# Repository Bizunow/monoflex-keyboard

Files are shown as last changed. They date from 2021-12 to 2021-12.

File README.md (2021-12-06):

# Monoflex keyboard

This repo contains case, plate, foam and PCB  design files for a Monoflex keyboard.

Case, plates and foam designed by me ([Bizunow](https://github.com/Bizunow)) and PCB designed by [keyten](https://github.com/KeyTen1).

Maintained by [Bizunow](https://github.com/Bizunow) & [ILWrites](https://github.com/pikeeb)

QMK Firmware source available on ILWrites' [Monoflex QMK branch](https://github.com/PiKeeb/qmk_firmware/tree/monoflex/keyboards/monoflex60)

Huge thanks to all, who helped me design this keyboard.

Licenced under WTFPL v2


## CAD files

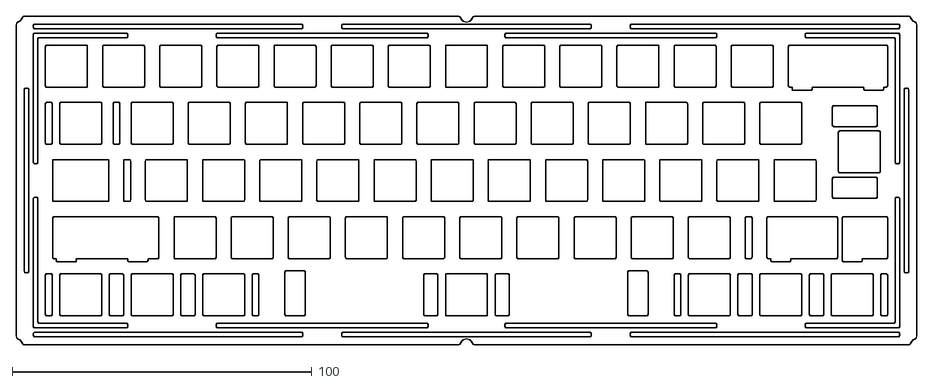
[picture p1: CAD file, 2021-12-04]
case_design/plates/carbon/full_plate_carbon_iso.dxf
300.1 x 109.6

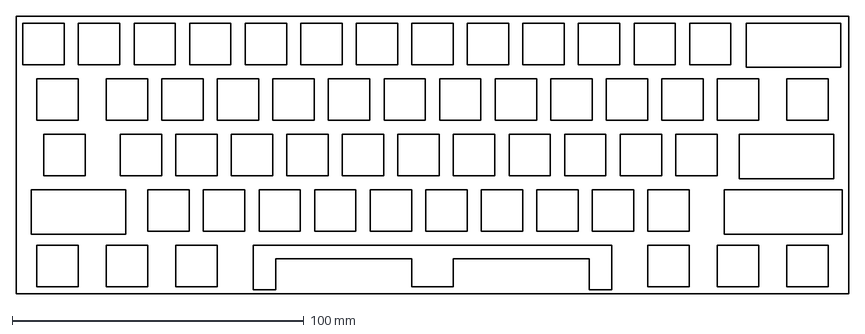
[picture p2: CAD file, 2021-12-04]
case_design/foam/foam_pcb_plate_full_tsangan.dxf
285.5 x 95.1 mm

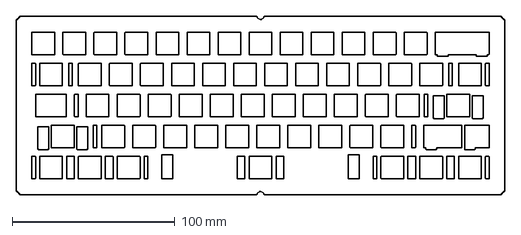
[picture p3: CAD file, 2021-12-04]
case_design/plates/pom/full_plate_pom_tsangan.dxf
300.1 x 109.6 mm

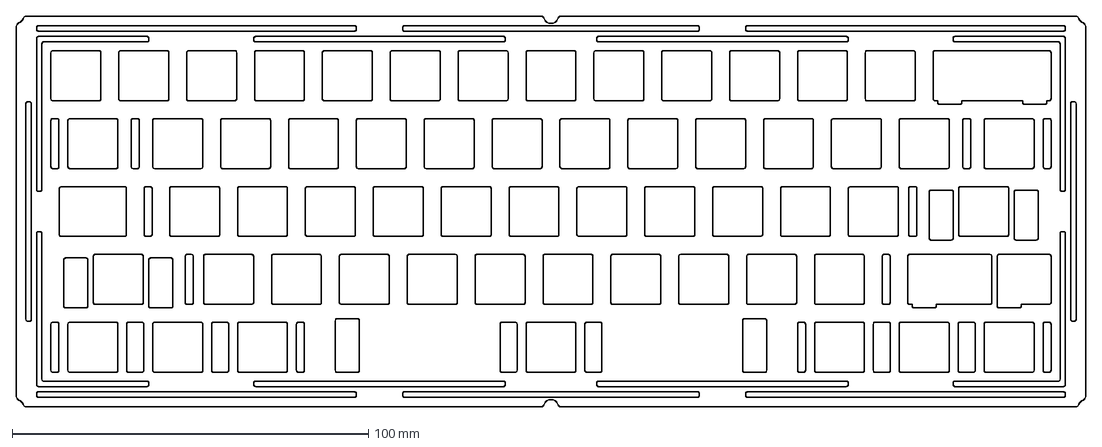
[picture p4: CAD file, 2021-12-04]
case_design/plates/carbon/full_plate_carbon.dxf
300.1 x 109.6 mm

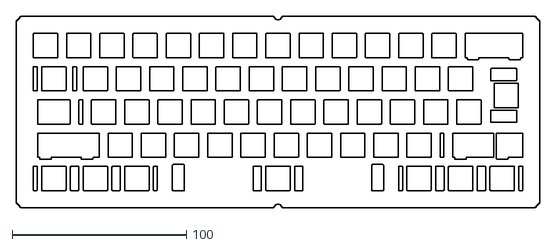
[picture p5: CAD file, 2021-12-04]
case_design/plates/pom/full_plate_pom_iso.dxf
300.1 x 109.6

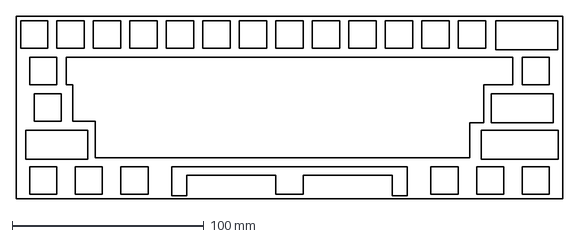
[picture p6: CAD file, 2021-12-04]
case_design/foam/foam_pcb_plate_half_tsangan.dxf
285.5 x 95.1 mm

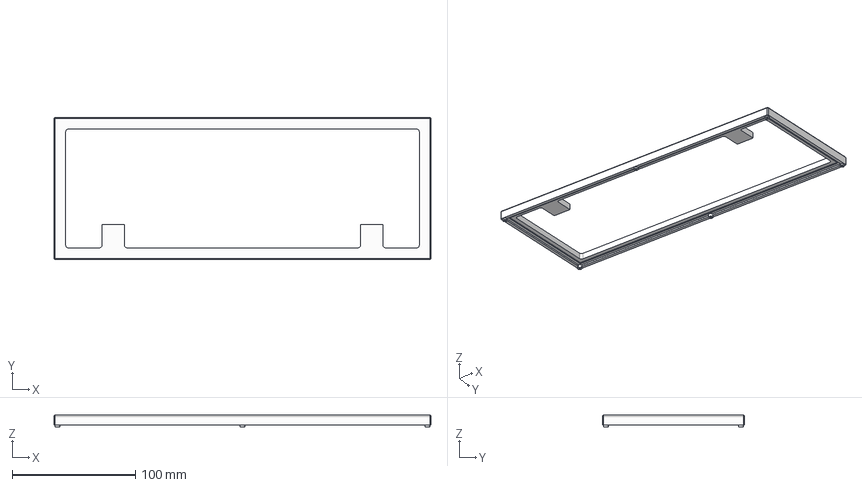
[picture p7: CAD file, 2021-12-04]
case_design/monoflex_top_wkl.step
305.8 x 115.2 x 9.60 mm

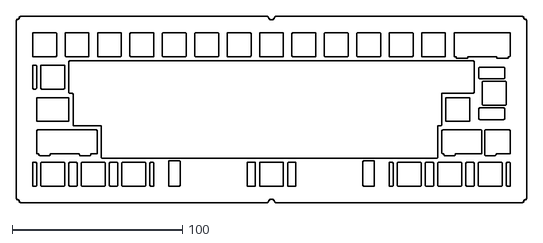
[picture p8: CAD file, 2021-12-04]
case_design/plates/pom/half_plate_pom_iso.dxf
300.1 x 109.6

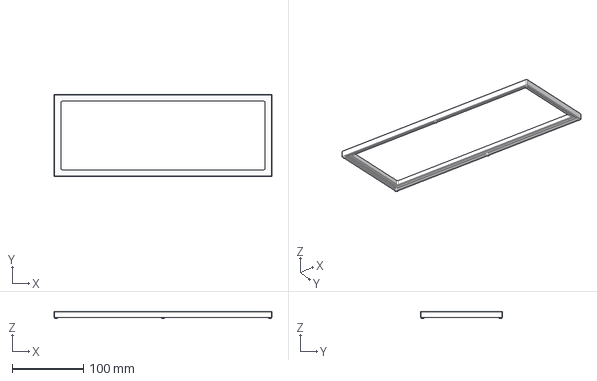
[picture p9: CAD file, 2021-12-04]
case_design/monoflex_top_ansi.step
305.8 x 115.2 x 9.60 mm

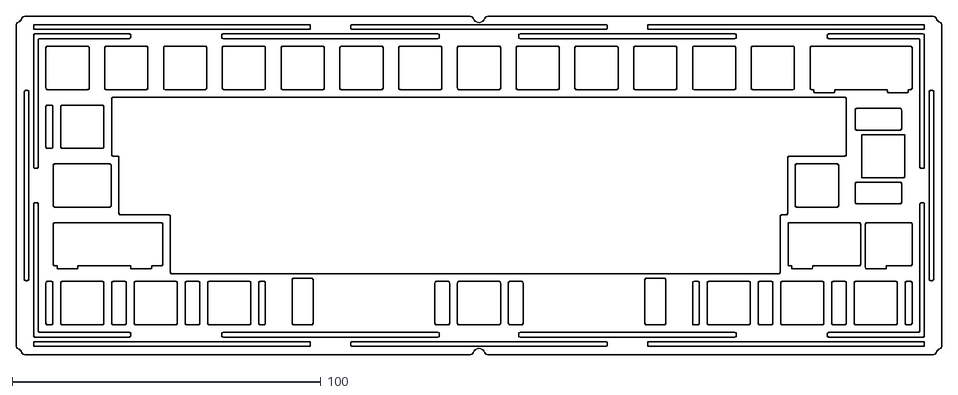
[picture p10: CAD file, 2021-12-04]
case_design/plates/carbon/half_plate_carbon_iso.dxf
300.1 x 109.6

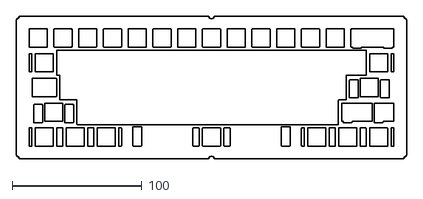
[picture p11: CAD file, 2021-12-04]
case_design/plates/pom/half_plate_pom_tsangan.dxf
300.1 x 109.6

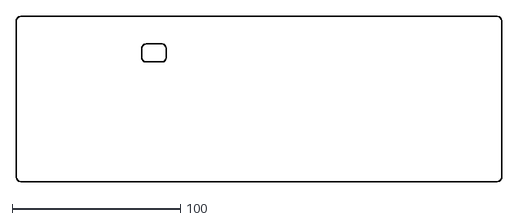
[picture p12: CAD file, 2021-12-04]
case_design/foam/foam_bottom.dxf
288.8 x 98.3

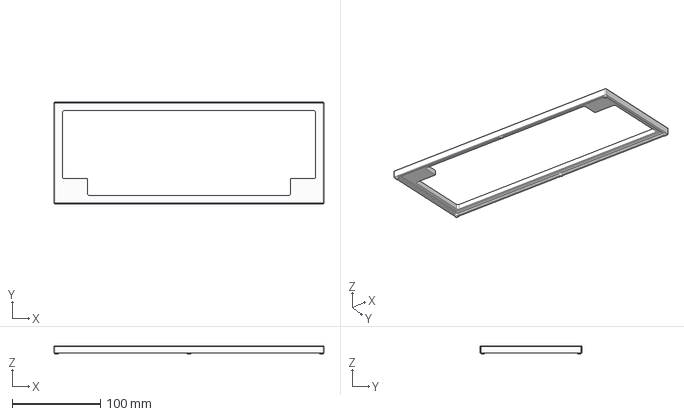
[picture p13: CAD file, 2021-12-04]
case_design/monoflex_top_hhkb.step
305.8 x 115.2 x 9.60 mm

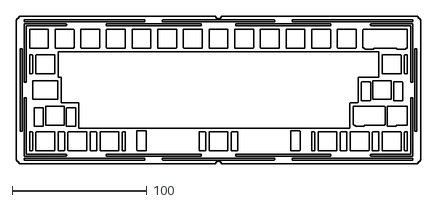
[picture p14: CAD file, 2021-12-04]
case_design/plates/carbon/half_plate_carbon.dxf
300.1 x 109.6

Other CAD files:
case_design/monoflex_bottom.step

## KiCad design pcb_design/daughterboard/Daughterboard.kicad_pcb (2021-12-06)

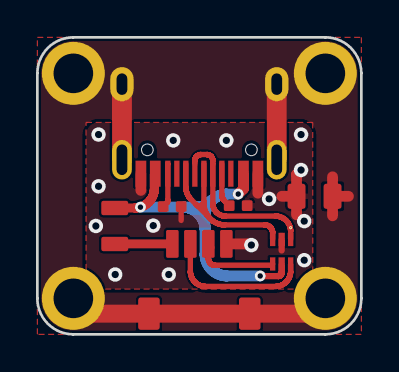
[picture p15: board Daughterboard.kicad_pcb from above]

Board: 2 copper layers, 18.0 x 16.5 mm, 11 parts (0 on the bottom side), 10 nets.

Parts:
F1: 350mA; Fuse_0805
J1: TYPE-C-31-M12_13; TYPE-C-31-M-12
J2: JST SH; JST_SH
J3, J4, J5, J6: Conn_01x01; M2_MountingHole
L1: 60Ω@100MHz; L_0805
R1, R2: 5.1kΩ; R_0402
U2: USBLC6-2P6; SOT-666

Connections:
+5V: F1.2, J2.1
D+: J2.3, U2.4
D-: J2.2, U2.6
DBUS+: J1.A6, J1.B6, U2.3
DBUS-: J1.A7, J1.B7, U2.1
GND: J1.A1, J1.B1, J2.4, L1.2, R1.2, R2.1, U2.2
GNDPWR: J1.S, J2.5, J2.6, J3.1, J4.1, J5.1, J6.1, L1.1
unnamed: J1.A5, R1.1
unnamed: J1.B5, R2.2
VBUS: F1.1, J1.A4, J1.B4, U2.5

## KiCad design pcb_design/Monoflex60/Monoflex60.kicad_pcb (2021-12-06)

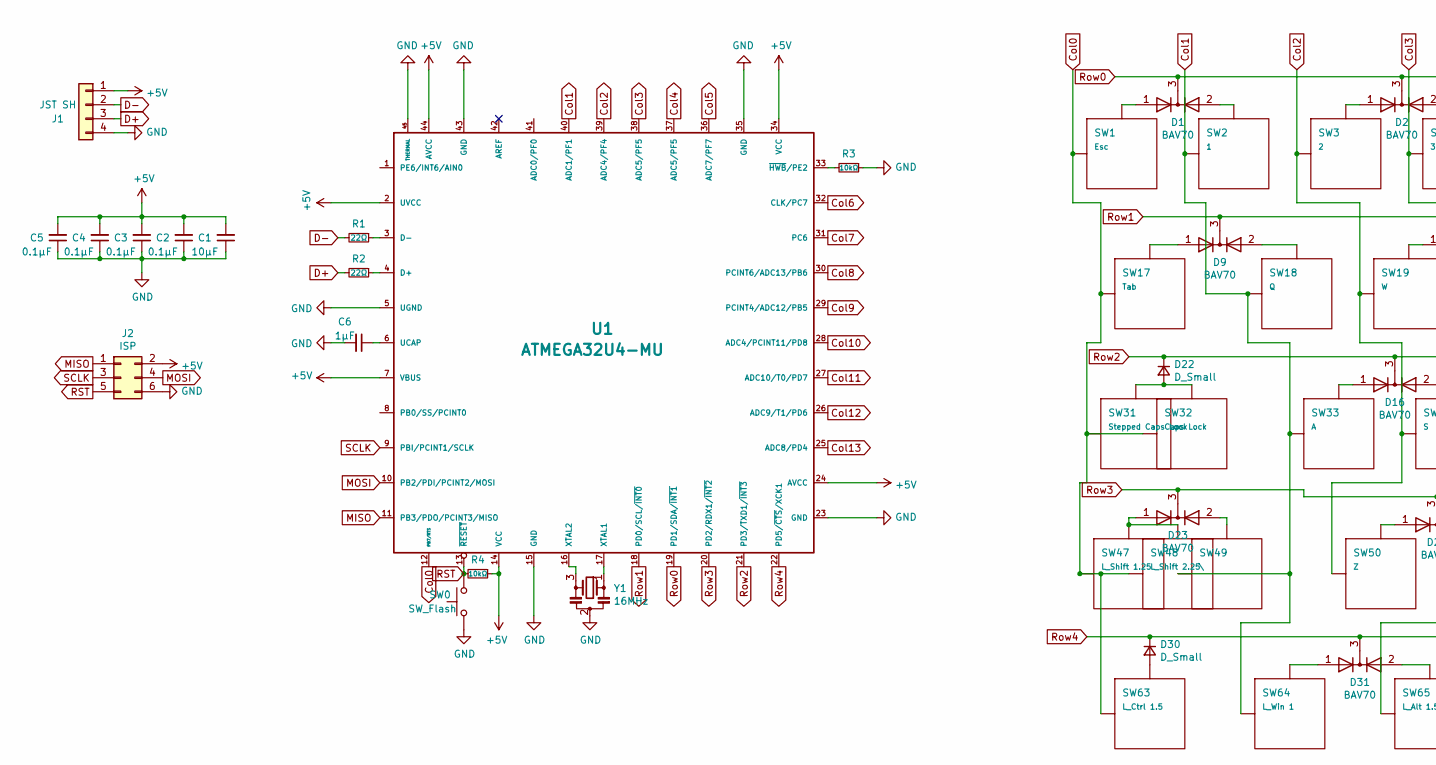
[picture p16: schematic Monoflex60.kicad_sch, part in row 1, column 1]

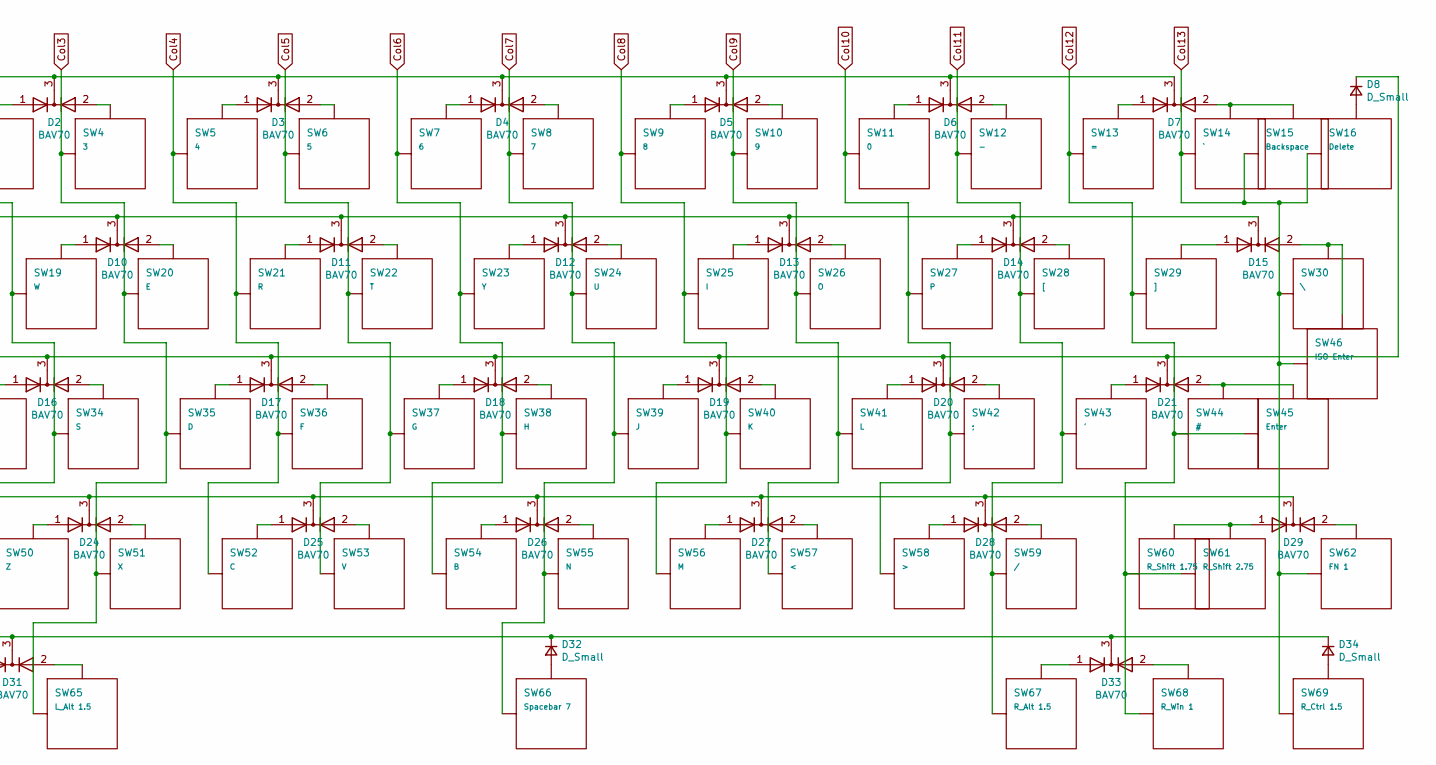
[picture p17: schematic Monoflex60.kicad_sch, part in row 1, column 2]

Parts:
C1: 10μF; C_0402
C2, C3, C4, C5: 0.1μF; C_0402
C6: 1μF; C_0402
D1, D2, D3, D4, D5, D6, D7, D9, D10, D11, D12, D13, D14, D15, D16, D17, D18, D19, D20, D21, D23, D24, D25, D26, D27, D28, D29, D31, D33: BAV70; SOT-23
D8, D22, D30, D32, D34: D_Small; D_SOD-323
J1: JST SH; JST_SH
J2: ISP; AVR-ISP
R1, R2: 22Ω; R_0402
R3, R4: 10kΩ; R_0402
SW0: SW_Flash; ALPSALPINE-SKSV
SW1: Esc; 1U
SW2: 1; 1U
SW3: 2; 1U
SW4: 3; 1U
SW5: 4; 1U
SW6: 5; 1U
SW7: 6; 1U
SW8: 7; 1U
SW9: 8; 1U
SW10: 9; 1U
SW11: 0; 1U
SW12: -; 1U
SW13: =; 1U
SW14: `; 1U
SW15: Backspace; 2U
SW16: Delete; 1U
SW17: Tab; 1.5U
SW18: Q; 1U
SW19: W; 1U
SW20: E; 1U
SW21: R; 1U
SW22: T; 1U
SW23: Y; 1U
SW24: U; 1U
SW25: I; 1U
SW26: O; 1U
SW27: P; 1U
SW28: [; 1U
SW29: ]; 1U
SW30: \; 1.5U
SW31: Stepped Caps Lock; 1.75U-stepped_Caps_Lock
SW32: Caps Lock; 1.75U
SW33: A; 1U
SW34: S; 1U
SW35: D; 1U
SW36: F; 1U
SW37: G; 1U
SW38: H; 1U
SW39: J; 1U
SW40: K; 1U
SW41: L; 1U
SW42: ;; 1U
SW43: '; 1U
SW44: #; 1U
SW45: Enter; 2.25U
SW46: ISO Enter; ISO
SW47: L_Shift 1.25; 1.25U
SW48: L_Shift 2.25; 2.25U
SW49: \; 1U
SW50: Z; 1U
SW51: X; 1U
SW52: C; 1U
SW53: V; 1U
SW54: B; 1U
SW55: N; 1U
SW56: M; 1U
SW57: <; 1U
SW58: >; 1U
SW59: /; 1U
SW60: R_Shift 1.75; 1.75U
SW61: R_Shift 2.75; 2.75U
SW62: FN 1; 1U
SW63: L_Ctrl 1.5; 1.5U
SW64: L_Win 1; 1U
SW65: L_Alt 1.5; 1.5U
SW66: Spacebar 7; 7U-reverse_stabs
SW67: R_Alt 1.5; 1.5U
SW68: R_Win 1; 1U
SW69: R_Ctrl 1.5; 1.5U
U1: ATMEGA32U4-MU; QFN-44-SMT
Y1: 16MHz; Resonator_SMD_muRata_CSTxExxV-3Pin_3.0x1.1mm

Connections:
+5V: C1.2, C2.2, C3.2, C4.2, C5.2, J1.1, J2.2, R4.1, U1.2 (UVCC), U1.7 (VBUS), U1.14 (VCC), U1.24 (AVCC), U1.34 (VCC), U1.44 (AVCC)
Col0: SW1.1 (Col), SW17.1 (Col), SW31.1 (Col), SW32.1 (Col), SW47.1 (Col), SW48.1 (Col), SW63.1 (Col), U1.12 (PB7/RTS)
Col1: SW2.1 (Col), SW18.1 (Col), SW33.1 (Col), SW49.1 (Col), SW64.1 (Col), U1.40 (ADC1/PF1)
Col2: SW3.1 (Col), SW19.1 (Col), SW34.1 (Col), SW50.1 (Col), U1.39 (ADC4/PF4)
Col3: SW4.1 (Col), SW20.1 (Col), SW35.1 (Col), SW51.1 (Col), SW65.1 (Col), U1.38 (ADC5/PF5)
Col4: SW5.1 (Col), SW21.1 (Col), SW36.1 (Col), SW52.1 (Col), U1.37 (ADC5/PF5)
Col5: SW6.1 (Col), SW22.1 (Col), SW37.1 (Col), SW53.1 (Col), U1.36 (ADC7/PF7)
Col6: SW7.1 (Col), SW23.1 (Col), SW38.1 (Col), SW54.1 (Col), U1.32 (CLK/PC7)
Col7: SW8.1 (Col), SW24.1 (Col), SW39.1 (Col), SW55.1 (Col), SW66.1 (Col), U1.31 (PC6)
Col8: SW9.1 (Col), SW25.1 (Col), SW40.1 (Col), SW56.1 (Col), U1.30 (PCINT6/ADC13/PB6)
Col9: SW10.1 (Col), SW26.1 (Col), SW41.1 (Col), SW57.1 (Col), U1.29 (PCINT4/ADC12/PB5)
Col10: SW11.1 (Col), SW27.1 (Col), SW42.1 (Col), SW58.1 (Col), U1.28 (ADC4/PCINT11/PD8)
Col11: SW12.1 (Col), SW28.1 (Col), SW43.1 (Col), SW59.1 (Col), SW67.1 (Col), U1.27 (ADC10/T0/PD7)
Col12: SW13.1 (Col), SW29.1 (Col), SW44.1 (Col), SW45.1 (Col), SW60.1 (Col), SW61.1 (Col), SW68.1 (Col), U1.26 (ADC9/T1/PD6)
Col13: SW14.1 (Col), SW15.1 (Col), SW16.1 (Col), SW30.1 (Col), SW46.1 (Col), SW62.1 (Col), SW69.1 (Col), U1.25 (ADC8/PD4)
D+: J1.3, R2.2
D-: J1.2, R1.2
GND: C1.1, C2.1, C3.1, C4.1, C5.1, C6.2, J1.4, J2.6, R3.1, SW0.1, U1.5 (UGND), U1.15 (GND), U1.23 (GND), U1.35 (GND), U1.43 (GND), U1.45 (THERMAL), Y1.2
MISO: J2.1, U1.11 (PB3/PDO/PCINT3/MISO)
MOSI: J2.4, U1.10 (PB2/PDI/PCINT2/MOSI)
unnamed: C6.1, U1.6 (UCAP)
unnamed: D1.1 (A), SW1.2 (Row)
unnamed: D1.2 (A), SW2.2 (Row)
unnamed: D2.1 (A), SW3.2 (Row)
unnamed: D2.2 (A), SW4.2 (Row)
unnamed: D3.1 (A), SW5.2 (Row)
unnamed: D3.2 (A), SW6.2 (Row)
unnamed: D4.1 (A), SW7.2 (Row)
unnamed: D4.2 (A), SW8.2 (Row)
unnamed: D5.1 (A), SW9.2 (Row)
unnamed: D5.2 (A), SW10.2 (Row)
unnamed: D6.1 (A), SW11.2 (Row)
unnamed: D6.2 (A), SW12.2 (Row)
unnamed: D7.1 (A), SW13.2 (Row)
unnamed: D7.2 (A), SW14.2 (Row), SW15.2 (Row)
unnamed: D8.2 (A), SW16.2 (Row)
unnamed: D9.1 (A), SW17.2 (Row)
unnamed: D9.2 (A), SW18.2 (Row)
unnamed: D10.1 (A), SW19.2 (Row)
unnamed: D10.2 (A), SW20.2 (Row)
unnamed: D11.1 (A), SW21.2 (Row)
unnamed: D11.2 (A), SW22.2 (Row)
unnamed: D12.1 (A), SW23.2 (Row)
unnamed: D12.2 (A), SW24.2 (Row)
unnamed: D13.1 (A), SW25.2 (Row)
unnamed: D13.2 (A), SW26.2 (Row)
unnamed: D14.1 (A), SW27.2 (Row)
unnamed: D14.2 (A), SW28.2 (Row)
unnamed: D15.1 (A), SW29.2 (Row)
unnamed: D15.2 (A), SW30.2 (Row), SW46.2 (Row)
unnamed: D16.1 (A), SW33.2 (Row)
unnamed: D16.2 (A), SW34.2 (Row)
unnamed: D17.1 (A), SW35.2 (Row)
unnamed: D17.2 (A), SW36.2 (Row)
unnamed: D18.1 (A), SW37.2 (Row)
unnamed: D18.2 (A), SW38.2 (Row)
unnamed: D19.1 (A), SW39.2 (Row)
unnamed: D19.2 (A), SW40.2 (Row)
unnamed: D20.1 (A), SW41.2 (Row)
unnamed: D20.2 (A), SW42.2 (Row)
unnamed: D21.1 (A), SW43.2 (Row)
unnamed: D21.2 (A), SW44.2 (Row), SW45.2 (Row)
unnamed: D22.2 (A), SW31.2 (Row), SW32.2 (Row)
unnamed: D23.1 (A), SW47.2 (Row), SW48.2 (Row)
unnamed: D23.2 (A), SW49.2 (Row)
unnamed: D24.1 (A), SW50.2 (Row)
unnamed: D24.2 (A), SW51.2 (Row)
unnamed: D25.1 (A), SW52.2 (Row)
unnamed: D25.2 (A), SW53.2 (Row)
unnamed: D26.1 (A), SW54.2 (Row)
unnamed: D26.2 (A), SW55.2 (Row)
unnamed: D27.1 (A), SW56.2 (Row)
unnamed: D27.2 (A), SW57.2 (Row)
unnamed: D28.1 (A), SW58.2 (Row)
unnamed: D28.2 (A), SW59.2 (Row)
unnamed: D29.1 (A), SW60.2 (Row), SW61.2 (Row)
unnamed: D29.2 (A), SW62.2 (Row)
unnamed: D30.2 (A), SW63.2 (Row)
unnamed: D31.1 (A), SW64.2 (Row)
unnamed: D31.2 (A), SW65.2 (Row)
unnamed: D32.2 (A), SW66.2 (Row)
unnamed: D33.1 (A), SW67.2 (Row)
unnamed: D33.2 (A), SW68.2 (Row)
unnamed: D34.2 (A), SW69.2 (Row)
unnamed: R1.1, U1.3 (D-)
unnamed: R2.1, U1.4 (D+)
unnamed: R3.2, U1.33 (~HWB/PE2)
unnamed: U1.16 (XTAL2), Y1.3
unnamed: U1.17 (XTAL1), Y1.1
RST: J2.5, R4.2, SW0.2, U1.13 (~RESET)
Row0: D1.3 (K), D2.3 (K), D3.3 (K), D4.3 (K), D5.3 (K), D6.3 (K), D7.3 (K), U1.19 (PD1/SDA/~INT1)
Row1: D9.3 (K), D10.3 (K), D11.3 (K), D12.3 (K), D13.3 (K), D14.3 (K), D15.3 (K), U1.18 (PD0/SCL/~INT0)
Row2: D8.1 (K), D16.3 (K), D17.3 (K), D18.3 (K), D19.3 (K), D20.3 (K), D21.3 (K), D22.1 (K), U1.21 (PD3/TXD1/~INT3)
Row3: D23.3 (K), D24.3 (K), D25.3 (K), D26.3 (K), D27.3 (K), D28.3 (K), D29.3 (K), U1.20 (PD2/RDX1/~INT2)
Row4: D30.1 (K), D31.3 (K), D32.1 (K), D33.3 (K), D34.1 (K), U1.22 (PD5/~CTS/XCK1)
SCLK: J2.3, U1.9 (PBI/PCINT1/SCLK)

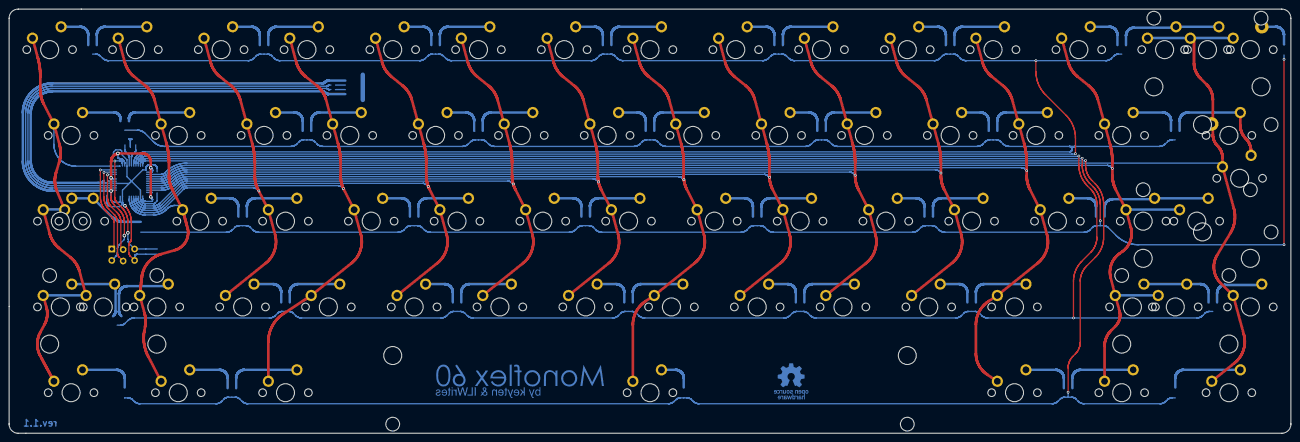
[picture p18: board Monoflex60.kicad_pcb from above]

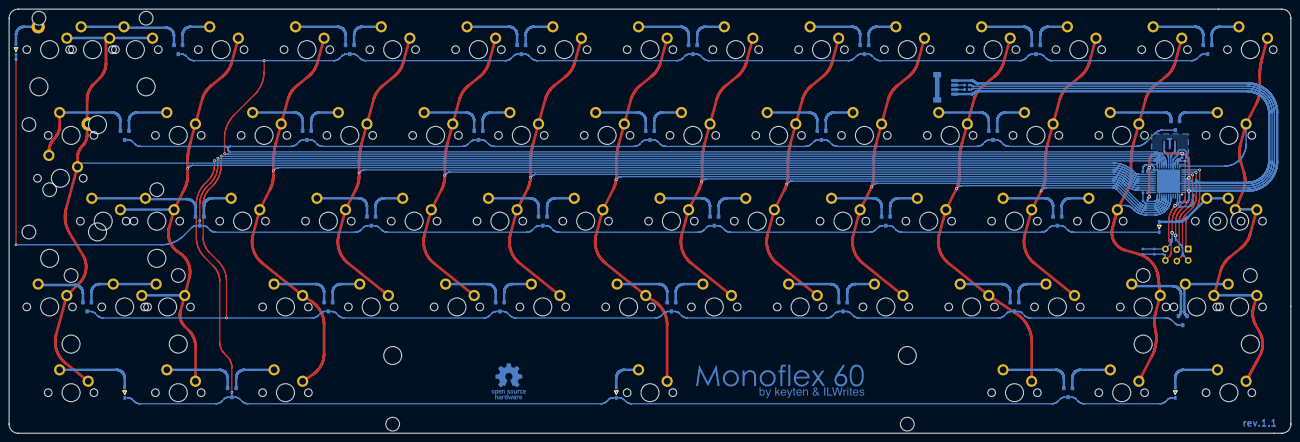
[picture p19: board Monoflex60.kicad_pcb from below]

Board: 2 copper layers, 284.7 x 94.2 mm, 118 parts (49 on the bottom side), 96 nets.
